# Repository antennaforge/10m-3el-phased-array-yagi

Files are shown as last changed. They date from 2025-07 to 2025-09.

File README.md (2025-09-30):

# 10m-yagi-phased-array

This compact lightweight HF antenna is based on the [3-element yagi design](https://antenna2.github.io/cebik/content/a10/ant53.html) by [LB Cebik, W4RNL (SK)](https://www.qcwa.org/w4rnl-13211-sk.htm) with slight modifications (antenna element materials). Many more of his works can be found [here](https://antenna2.github.io/cebik/content/bookant.html) and [here](https://github.com/antenna2/cebik/tree/main).

## Modifications
1. Use of combination of tent poles and arrow shafts for dipole elements.
2. Use of 3d printed parts
3. Current choke
4. Truss support

## Table of contents
1. Introduction
2. [Bill of materials](Bill-of-materials.md)
3. [Element construction](Elements.md)
4. [Choke](Choke.md)
4. [Phasing harness](Phasing-harness.md)
5. [Truss](Truss.md)
6. [Tuning](Tuning.md)
7. [Testing](Testing.md)
8. [References](References.md)

Have fun learning from building this one.

73 de Herman Tolentino, KQ4ZGQ

## License

- Project design files are released under the [CERN Open Hardware Licence v2 Strongly Reciprocal](LICENSE.md).
- Original LB Cebik reference materials cited above are maintained at [antenna2/cebik](https://github.com/antenna2/cebik) and are shared under the MIT License.

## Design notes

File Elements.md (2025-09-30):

# Element construction - Overview

There are three dipoles (elements):
1. Director Dipole. Based on Cebik medium duty design, this dipole is 191 inches long. A half element is 95.5 inches long. (Prototype half dipole is 95 inches.)
2. Forward-fed Dipole (Driver 2 or D2) 194 inches long, half is 97. (Prototype half dipole is 100.25 inches.)
3. Rear-fed Dipole (Driver 1 or D1) 206 inches long, half is 103. (Prototype half dipole is 108.5 inches.)

For sources of materials for antenna elements, see [Bill of materials](Bill-of-materials.md)

## Connectors
1. Connector 1: Online Metals 1/4 inch OD, 0.035 inch thick aluminum tube cut to 4 inches
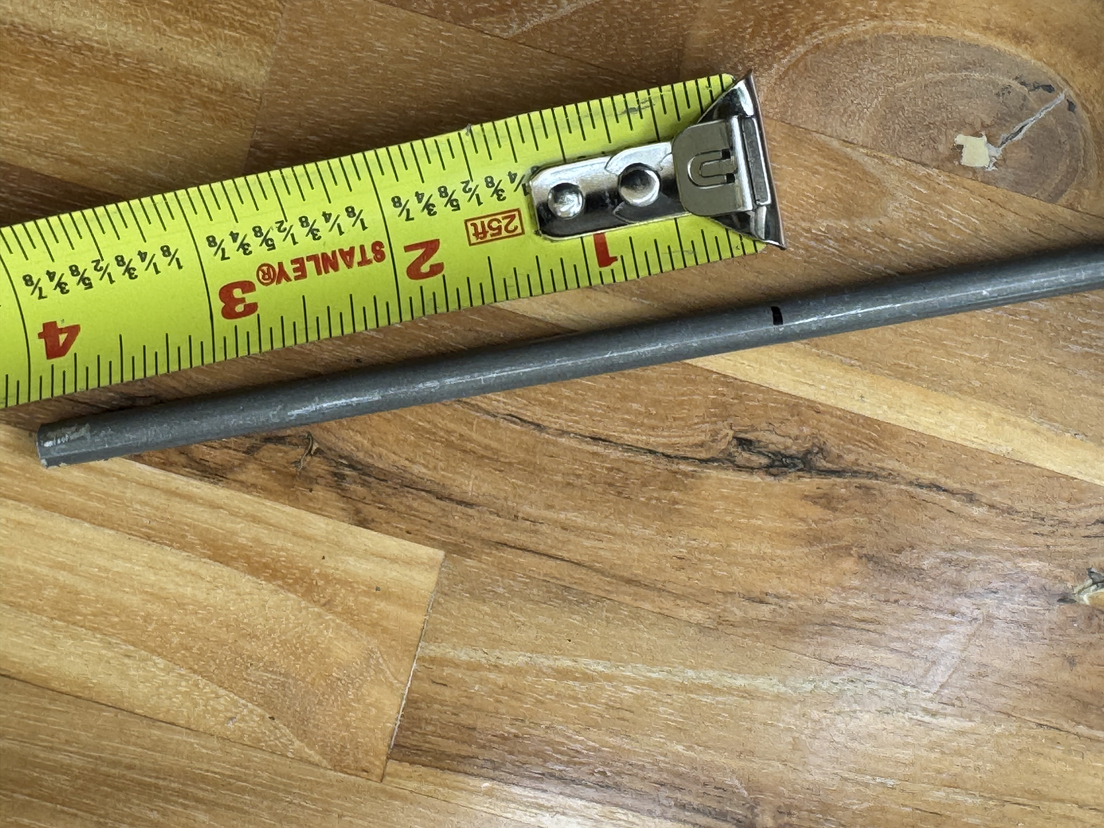
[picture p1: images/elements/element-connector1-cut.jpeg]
 
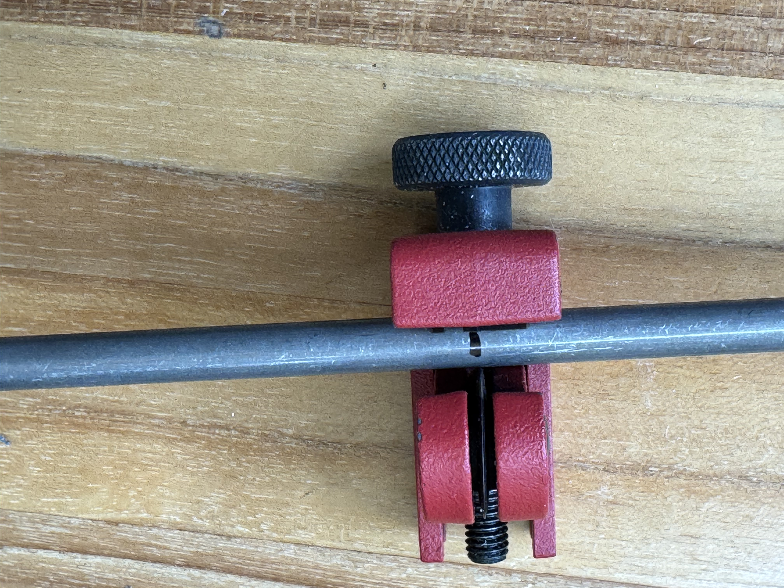
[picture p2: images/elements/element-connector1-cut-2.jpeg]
 

2. Connector 2: Online Metals 1/4 inch OD, 0.035 inch thick aluminum tube cut to 3 inches

## Shims

1. Shim 1: Copper tape shim, cut to 2 inches
2. Shim 2: Copper tape shim, cut to 4 inches (for Connector 1)
3. Shim 3: Copper tape shim, cut to 3 inches (for Connector 2)
4. Shim 4: Copper sheet cut to 1.25 inch by 0.25 inch lengths
 
## Element Segments

Table 1. Element lengths for modified Cebik antenna. All dimensions are in inches. Two inches of the Mid 1 segments overlaps with the root tubes. The tip tubes are used for tuning and can slide into the Mid 3 segments to vary the dipole lengths. 
| Dipole	  | Root	 | Mid 1 | Mid 2 | Mid 3 | Tip |
|---|---|---|---|---|-----|
| Director	  | 13.5	 | 30	 | 30	 | 15	 | 12  |
| Forward-fed |	| 14.5	 | 30	 | 30	 | 16	 | 12  |
| Rear-fed	  | 14.5	 | 30	 | 30	 | 25	 | 12  |

There are 4 segments in each half of the Director dipole. All "Mid" segments are arrow shafts. The root tube is a tent pole. The tip tube is a smaller diameter aluminum tube that slides inside the last arrow shaft.

1. Root segment (tent pole): Cut to 13.5 inches
2. Mid 1 segment (arrow shaft): Keep original length at 30 inches. Two inches of the root side is stripped and covered with 4 sheets of Shim 1 and slides into the tent pole.
3. Mid 2 segment (arrow shaft): Keep original length at 30 inches. This connects to Mid 1 using Connector 1 which is covered with Shim 2. Connector 1 has a 2 inch overlap on each side.   
4. Mid 3 segment (arrow shaft): Cut to 15 inches. This connects to Mid 2 using Connector 2. Connector 2 is covered with 1 and 1/3 sheets of Shim 3 before sliding Mid 3 and Mid 2 over it. Connector 2 has 1.5 inch overlap on each side. 
5. Tip segment (6 mm K&S aluminum tube): Cut to 12 inches. This slides into Mid 3 using Shim 1. This will be the tuning tube, all others are fixed. See Cebik antenna element lengths table below.

## Forward-fed Dipole

There are 4 segments in each half of the Forward-fed dipole. All "Mid" segments are arrow shafts. The root tube is a tent pole. The tip tube is an aluminum tube that slides inside the last arrow shaft.

1. Root segment (tent pole): Cut to 14.5 inches
2. Mid 1 segment (arrow shaft): Keep original length at 30 inches. Two inches of the root side is stripped and covered with 4 sheets of Shim 1 and slides into the tent pole.
3. Mid 2 segment (arrow shaft): Keep original length at 30 inches. This connects to Mid 1 using Connector 1 which is covered with Shim 2. Connector 1 has a 2 inch overlap on each side.   
4. Mid 3 segment (arrow shaft): Cut to 15.5 inches. This connects to Mid 2 using Connector 2. Connector 2 is covered with 1 and 1/3 sheets of Shim 3 before sliding Mid 3 and Mid 2 over it. Connector 2 has 1.5 inch overlap on each side. 
5. Tip segment (6 mm K&S aluminum tube): Cut to 12 inches. This slides into Mid 3 using Shim 1. This will be the tuning tube, all others are fixed. See Cebik antenna element lengths table below.

## Rear-fed Dipole

There are 5 segments in each half of the Rear-fed dipole. All "Mid" segments are arrow shafts. The root tube is a tent pole. The tip tube is an aluminum tube that slides inside the last arrow shaft.

1. Root segment (tent pole): Cut to 14.5 inches
2. Mid 1 segment (arrow shaft): Keep original length at 30 inches. Two inches of the root side is stripped and covered with 4 sheets of Shim 1 and slides into the tent pole.
3. Mid 2 segment (arrow shaft): Keep original length at 30 inches. This connects to Mid 1 using Connector 1 which is covered with Shim 2. Connector 1 has a 2 inch overlap on each side.   
4. Mid 3 segment (arrow shaft): Cut to 18.5 inches. This connects to Mid 2 using Connector 2. Connector 2 is covered with 1 and 1/3 sheets of Shim 3 before sliding Mid 3 and Mid 2 over it. Connector 2 has 1.5 inch overlap on each side. 
5. Tip segment (6 mm K&S aluminum tube): Cut to 12 inches. This slides into Mid 3 using Shim 1. This will be the tuning tube, all others are fixed. Pull the tip in or out of Mid 3 to adjust half-element length. See Cebik antenna element lengths table in [Tuning](Tuning.md) Table 1.

# Preparing elements and Connectors

## Burring and stripping

1. Burr the insides of both ends of arrow shafts  
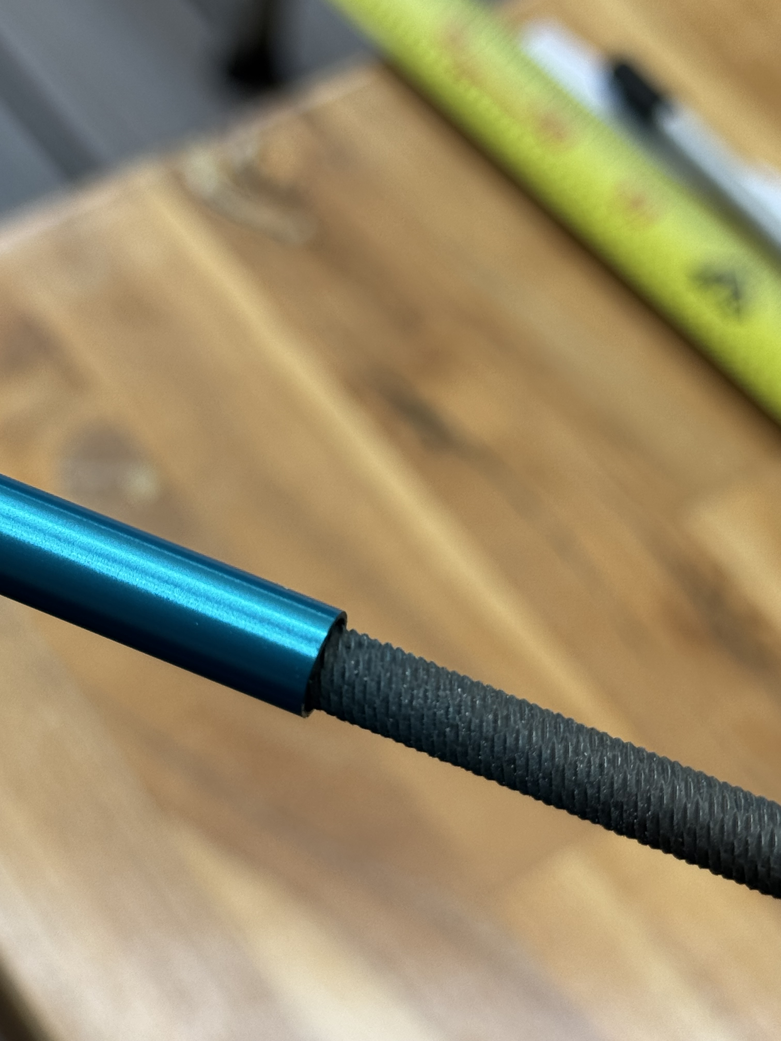
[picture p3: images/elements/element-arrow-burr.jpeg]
 
2. Test that the burring created a conductive path for connectors to work. 
 
3. Do the same for the element side of the root tube, the tent pole. One inch of the boom side of the tent pole is stripped. Test connections as well. 
4. Strip 2 inches from one end of each Mid 1 segment (arrow shaft) to ensure proper fit into the tent pole root segment.

## Stripping

1. Strip 2 inches from the root end of each Mid 1 segment (arrow shaft) to create a snug fit inside the tent pole  
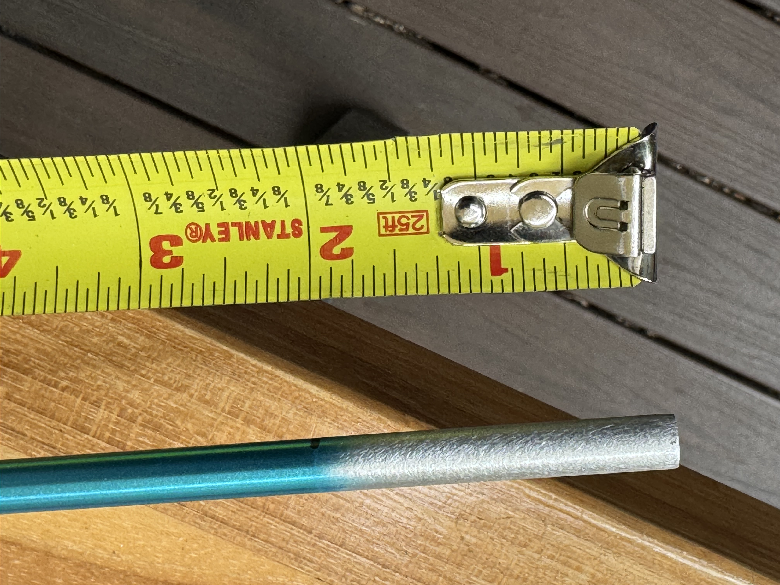
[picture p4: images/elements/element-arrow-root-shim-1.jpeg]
 
2. Apply 4 sheets of Shim 1 (copper tape) around the stripped section before insertion
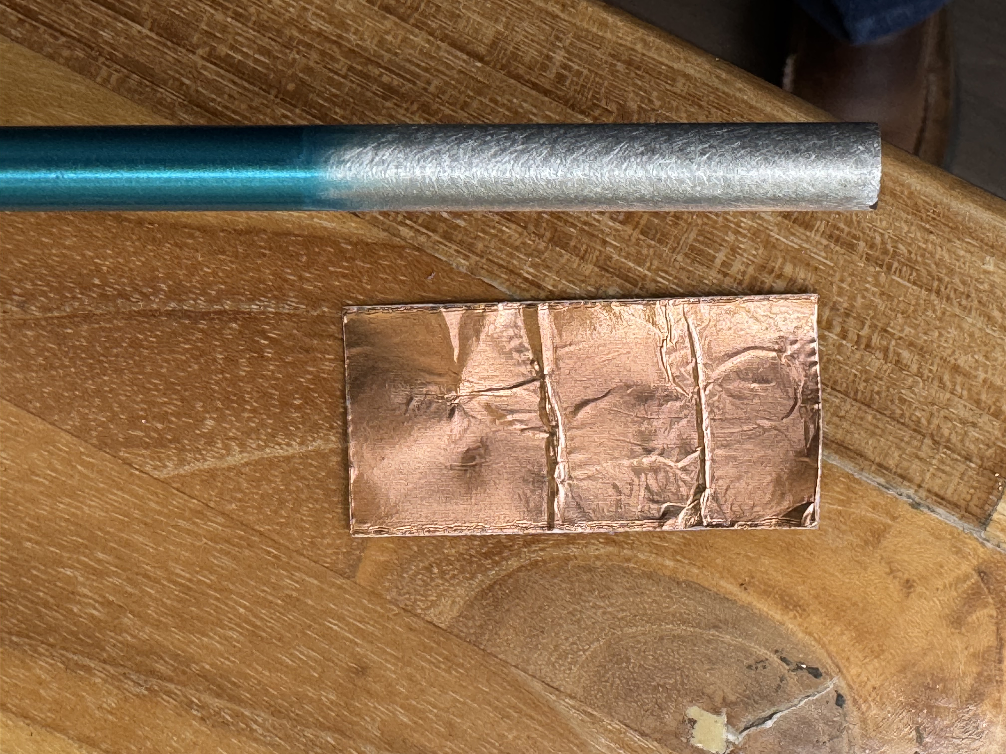
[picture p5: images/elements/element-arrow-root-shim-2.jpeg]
 
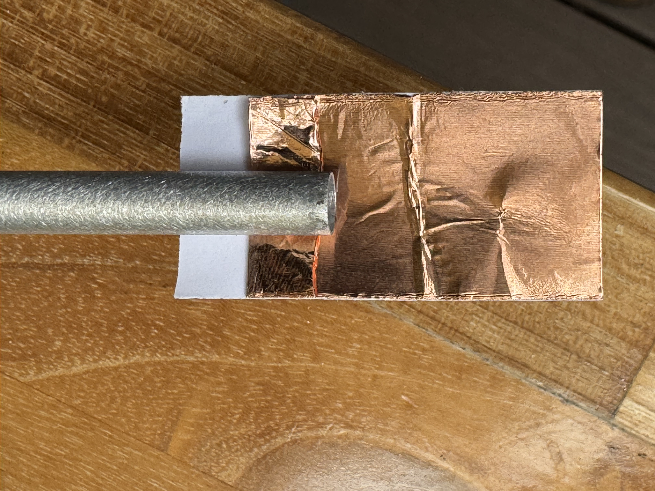
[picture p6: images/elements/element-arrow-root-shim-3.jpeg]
 
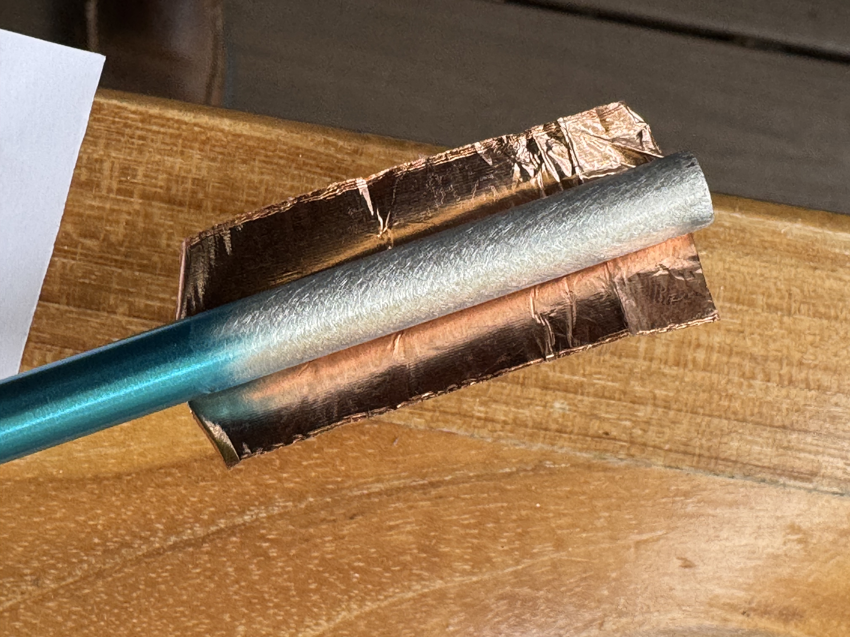
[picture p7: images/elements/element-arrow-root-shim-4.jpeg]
 

3. Ensure snug fit and test all connections to ensure electrical continuity before final assembly.
4. Mark the insertion depth on each segment to ensure consistent lengths assembly and re-assembly.

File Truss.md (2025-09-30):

# Truss

The purpose of the truss system is to prevent excessive sagging of the 3 elements.

## Setting up the truss mast
1. Cut arrow shaft to 15-inch length x 6 (2 per dipole element)
2. Label the pair of masts for each element.

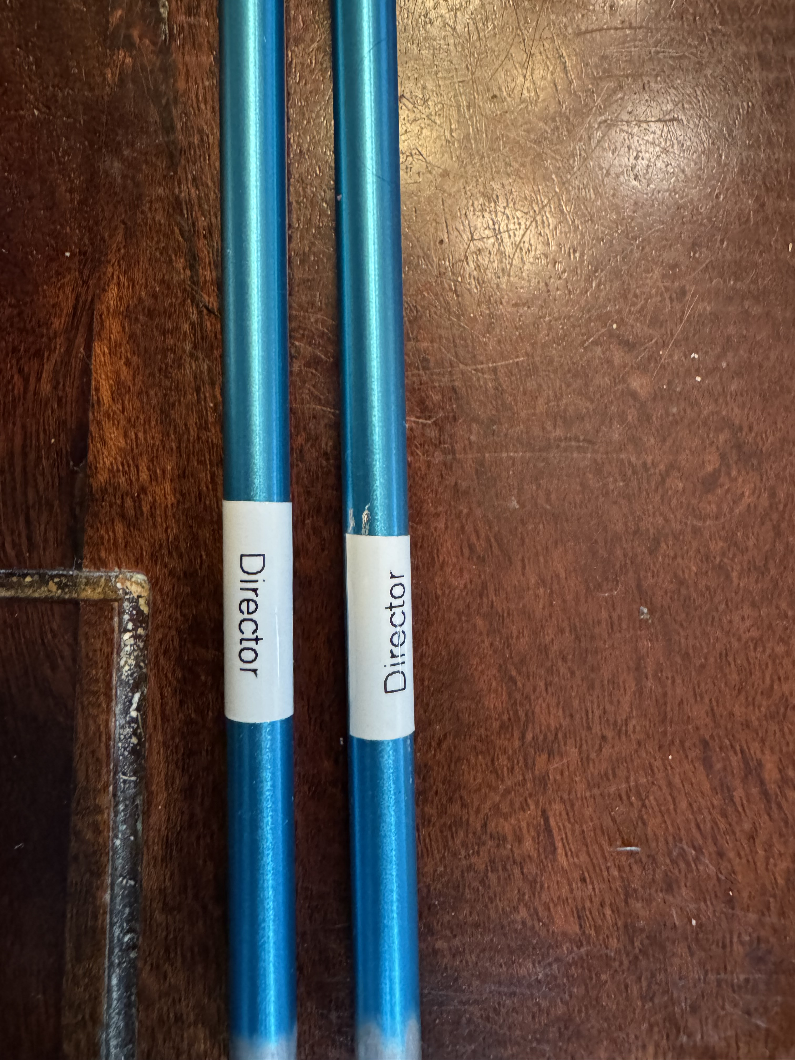
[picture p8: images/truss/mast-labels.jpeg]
 

3. Attach the truss clamp assembly to the mast pair for each element.

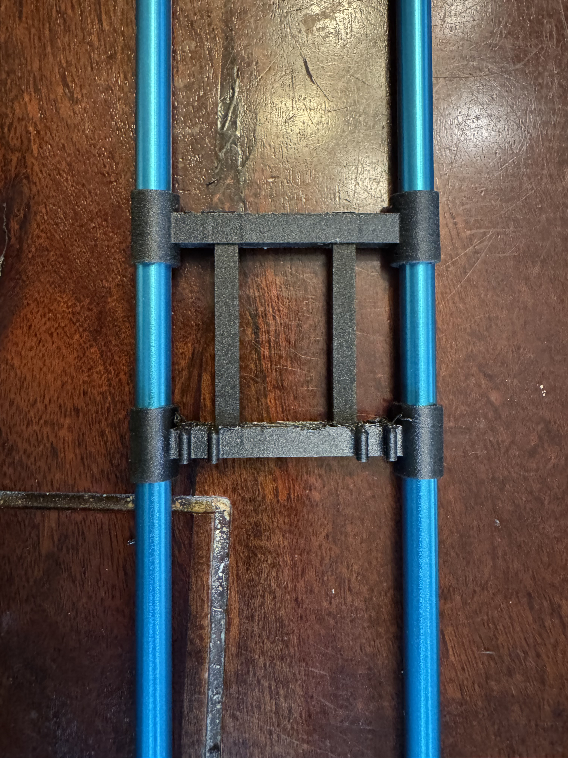
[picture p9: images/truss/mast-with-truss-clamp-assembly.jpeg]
 

## Setting up the paracord

### Paracord and tensioner

1. Cut paracord to lengths corresponding to the elements below:

| Element | Length, inches |
|---|---|
| Rear-fed | 160 |
| Forward-fed | 148 |
| Director | 146 |

2. Attach the tensioner to the ends of each cord using a square knot.

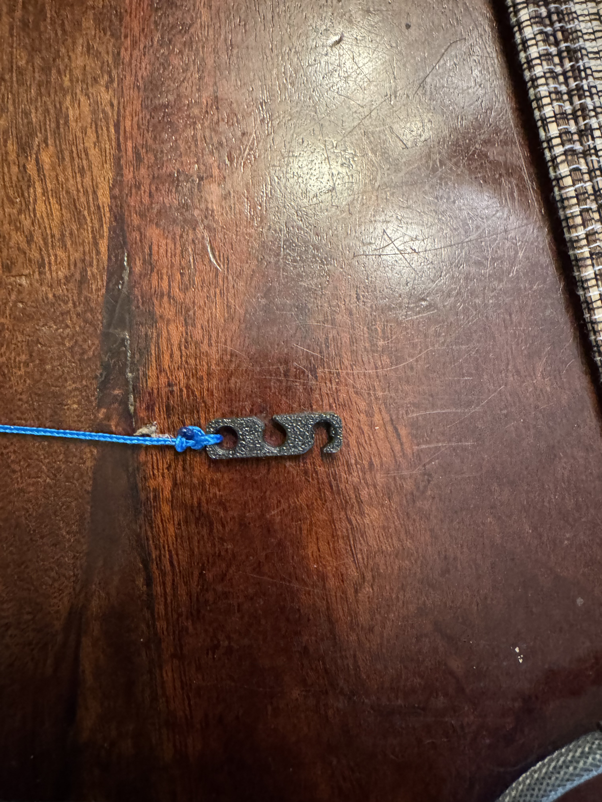
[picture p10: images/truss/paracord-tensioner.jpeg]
 

3. Place the cord clamp on the element half a certain distance from boom according to the table below. Fix the each element cord clamp with a 4-40 machine screw and lock nut - make sure clamps for both element halves are equidistant from the boom.

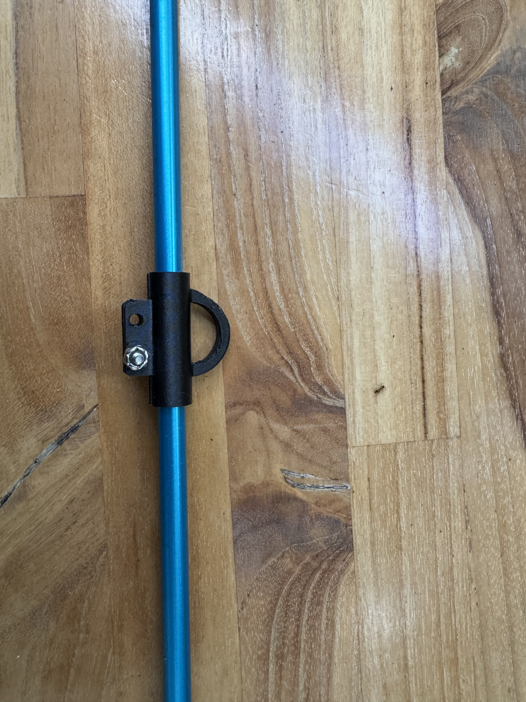
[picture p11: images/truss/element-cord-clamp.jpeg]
 

| Element | Length, inches |
|---|---|
| Rear-fed | 63 |
| Forward-fed | 61 |
| Director | 55 |

4. During assembly insert each mast pair into the corresponding tubes on the truss base.

5. During disassembly, just clip the tensioner on the mast clip to prevent accidental unwinding and messy cord tangles.

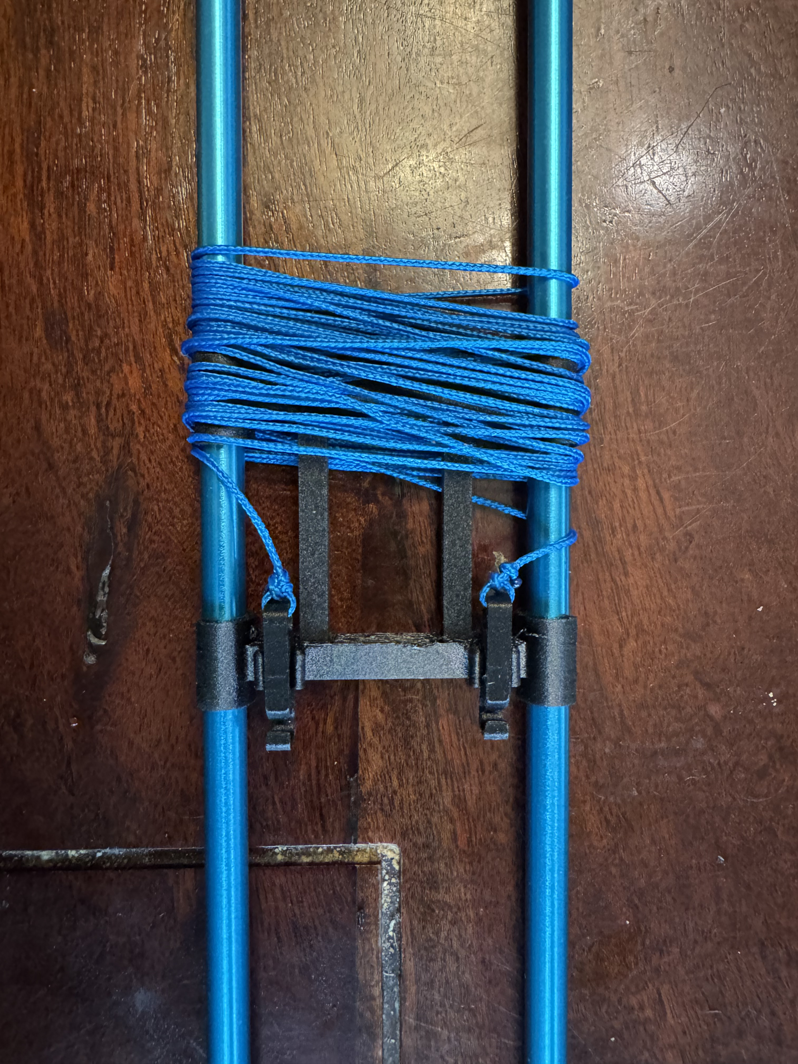
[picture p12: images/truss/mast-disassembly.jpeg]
 

6. Disassembled masts with cord wrapped around each pair. 



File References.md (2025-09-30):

# References

1. [Cebik LB (W4RNL, SK) (2008). A Short Boom, Wideband, *Three Element Yagi for 10 Meters*.](https://www.arrl.org/files/file/Product%20Notes/Antenna_Compendium_Vol_8/Cebik2a.pdf) Last accessed 19 July 2025.
2. Common mode chokes (G3TXQ) - http://www.karinya.net/g3txq/chokes/#measurement. Last accessed 30 Sept 2025.

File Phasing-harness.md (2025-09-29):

# Phased array configuration

The phased array is based on the Cebik antenna described in the [References](References.md) section. Follow wire specs, spaving and building instructions closely.

**Figure 1.** Phasing harness on the antenna boom. Note the half-twist somewhere in the middle.  
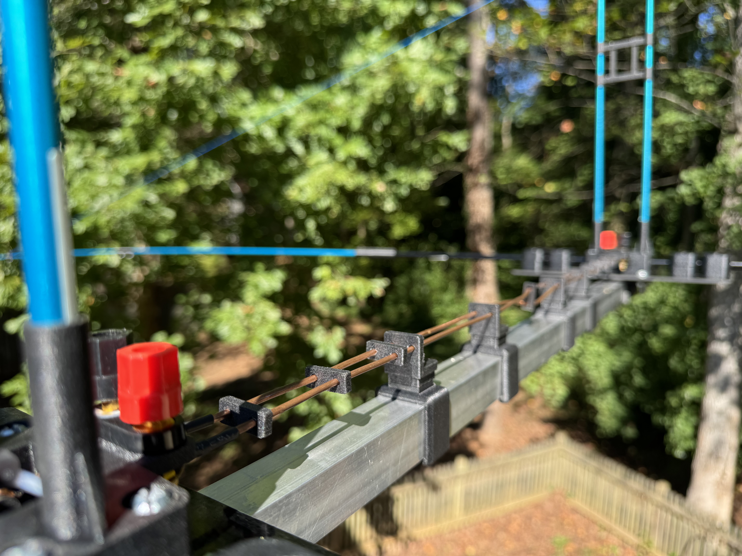
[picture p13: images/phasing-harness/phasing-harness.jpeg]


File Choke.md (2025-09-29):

# Building the current choke

1. See [Bill of Materials](Bill-of-materials.md) for Choke
2. Wind 7-8 turns of RG400 on an FT240-31 ferrite core. Keep the coax pigtails as short as possible. (See Figure 1 below) 
3. Add ferrite beads on the feedpoint coax. (See Figure 2a and 2b)

**Figure 1.** Ferrite core choke balun on the antenna  


**Figure 2a.** Ferrite beads on the feedpoint coax  


**Figure 2b.** Ferrite beads on the feedpoint coax  


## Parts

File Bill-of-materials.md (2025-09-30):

# Bill of materials

## Antenna Dipole Elements

1. Tent poles (1 pack, good for 2 antennas): https://www.amazon.com/dp/B0D17T46FL?th=1
2. Arrow shafts / truss masts (pack of 12, need 2 sets): https://www.amazon.com/dp/B07L5M5MLR
3. Aluminum tube (tip) and element connectors, 1/4 inch OD, 0.035 inch thick, 3 feet x 5: https://www.mcmaster.com/catalog/131/4227/9056K61. For tuning tips, cut 3 of 3 foot tubes into 2 equal halves. Use the remaining 2 3-foot tubes for arrow shaft connectors.   
4. Antenna boom, aluminum square tube, 1 inch x 1 inch x 6 feet: https://www.mcmaster.com/catalog/131/4228/6546K53. Cut to 5 feet length.

## Truss
1. Paracord (see [Truss.md](Truss.md) for estimating cord lengths) - https://www.amazon.com/dp/B0D1DHBP4F
2. Arrow shafts (see above)

## Copper conductors

1. Copper sheet: https://www.amazon.com/uxcell-Flashing-Electricity-Projects-Multiple/dp/B0C55HNVV6
2. Copper tape: https://www.amazon.com/dp/B097HHJQPS
3. Copper wire 18AWG: https://www.amazon.com/dp/B08QG84CWQ
4. Copper wire 10AWG: https://www.amazon.com/dp/B0CC5742QQ
   
## Screws and Brass Inserts
1. Screws  
   1.1 Element clamps: 10-32, 1.25 inches x 24 - https://www.amazon.com/Stainless-Phillips-Machine-Bolt-Dropper/dp/B07D1L49NR   
   1.2 Truss base: 10-32, 1.5 inches x 12 - https://www.amazon.com/Glvaner-Thread-Phillips-Machine-Stainless/dp/B09B75WRXX  
   1.3 Truss base, terminal: 10-32, 3/4 inch x 6 - https://www.amazon.com/Phillips-Machine-Stainless-Thread-RoyceMart/dp/B08GH98YPS/    
   1.4 Element plate to boom clamp: 10-32, 3/4 inch x 12 (same as above)  
   1.5 Boom clamp brass inserts: 8-32, 1/2 inch x 10 - https://www.amazon.com/Phillips-Machine-Screws-Stainless-Quantity/dp/B0894BY3SF/  
   1.6 Boom to mast clamp: 10-32, 1.5 inches x 4 (same as 1.2)  
   1.7 Element clamps: 4-40, 1/2 inch x 54 - https://www.amazon.com/dp/B09B74Y13V?   
   1.8 Lock nuts, 10-32 -  https://www.amazon.com/Vifmy-Insert-Locknuts-Stainless-Standard/dp/B0CPHW89YP/  
   1.9 Lock nuts, 4-40 - https://www.amazon.com/dp/B085N483D1  

2. Brass inserts: 8-32, 1/4 inch x 8 - https://www.amazon.com/ruthex-8-32-Threaded-Inserts-RX-8-32x8-1/dp/B0CG4K9FM5/

## Choke
1. Ferrite toroid 240-31 - https://www.amazon.com/dp/B0F6DG2H5S  
2. RG400 coax - https://www.amazon.com/dp/B08N17KGK1  
3. SO239 connector - https://www.amazon.com/dp/B08F772R48  
5. Terminal lug, M5 - https://www.amazon.com/dp/B0DC6JP5BW  
6. Ferrite beads on coax - https://www.amazon.com/dp/B0C9QXBS3J
   
## 3D Filaments
1. PETG-CF -

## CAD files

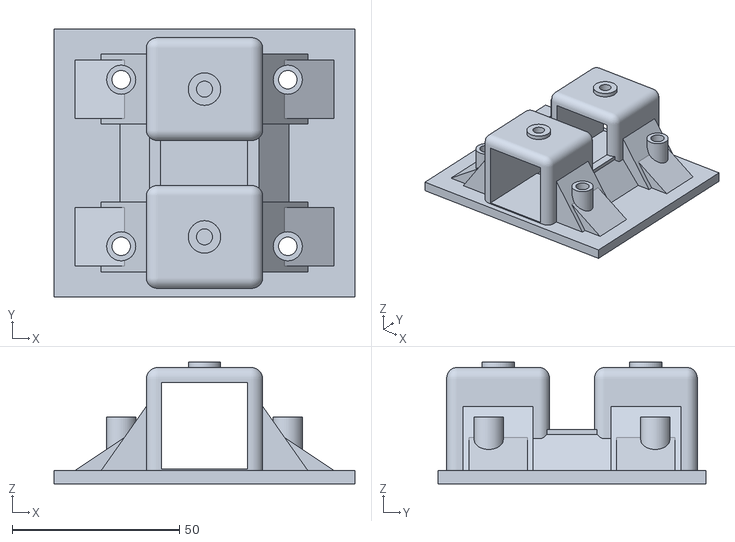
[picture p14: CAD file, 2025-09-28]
stl/10m-yagi-boom-mast-clamp.stl
90.0 x 80.0 x 36.4

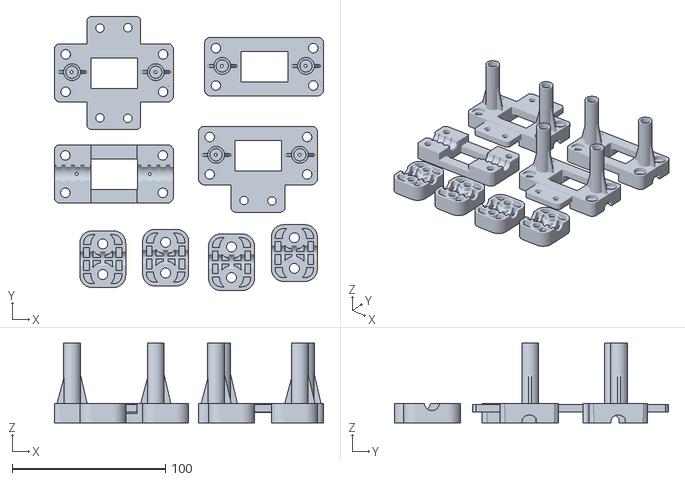
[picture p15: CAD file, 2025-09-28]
stl/10m-yagi-truss-base-V2.stl
175.5 x 178.9 x 52.0

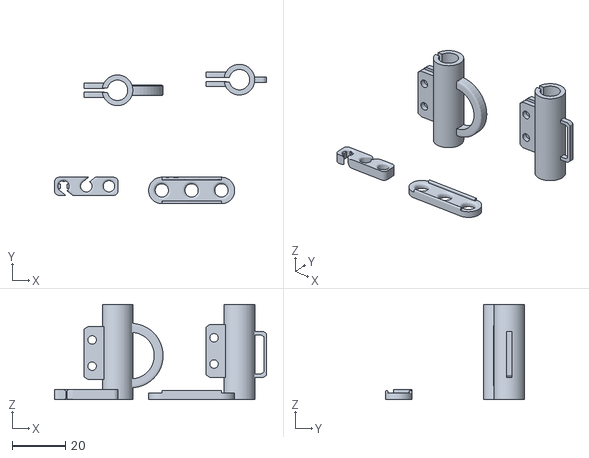
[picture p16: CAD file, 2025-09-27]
stl/10m-yagi-rope-tensioner.stl
80.0 x 52.6 x 36.0

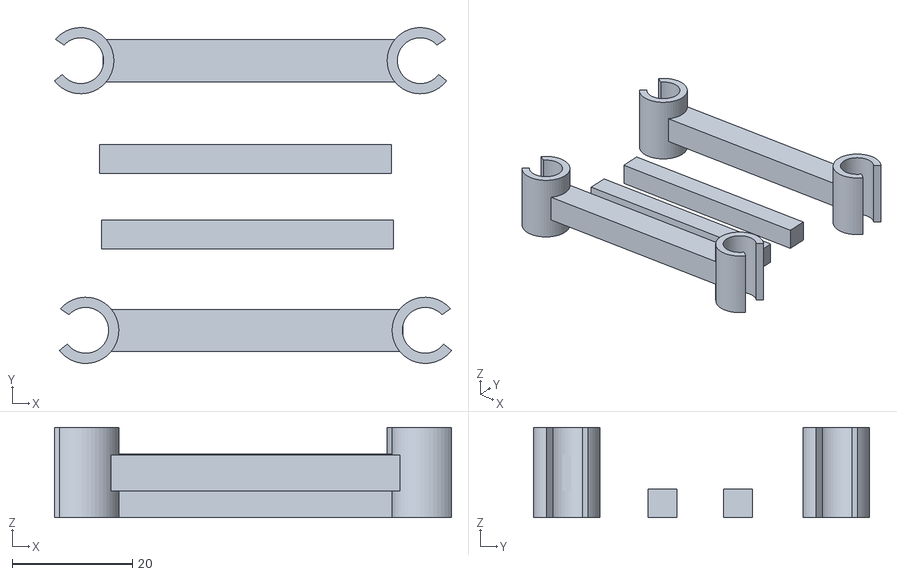
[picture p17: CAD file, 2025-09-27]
stl/10m-yagi-truss-accessories.stl
65.9 x 55.8 x 15.0

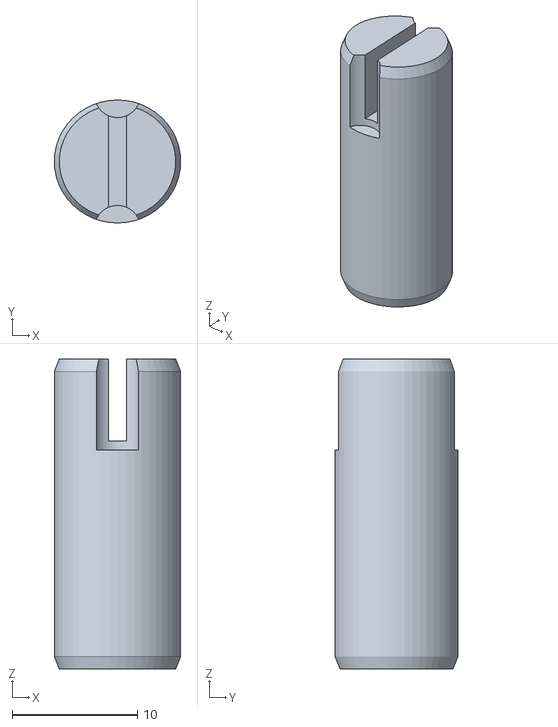
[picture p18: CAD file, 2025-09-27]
stl/10m-yagi-petg-element-cap.stl
10.1 x 9.82 x 24.8

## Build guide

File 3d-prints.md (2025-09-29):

# 3D-Printed Parts

## Truss parts
1. Truss cap  
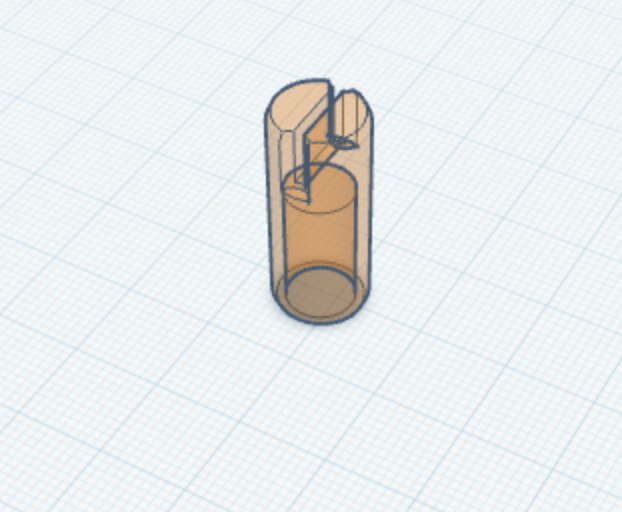
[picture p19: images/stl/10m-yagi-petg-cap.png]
[](stl/10m-yagi-petg-element-cap.stl)
2. Truss accessories  
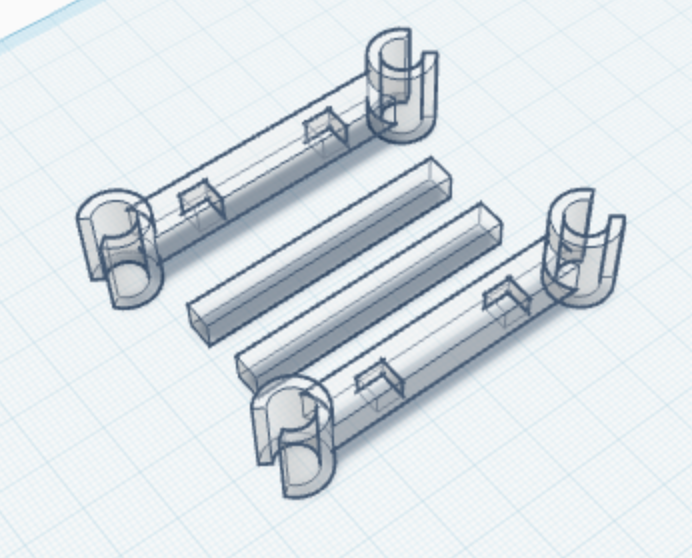
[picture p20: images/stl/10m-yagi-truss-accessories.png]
[](stl/10m-yagi-truss-accessories.stl)
3. Rope tensioner  
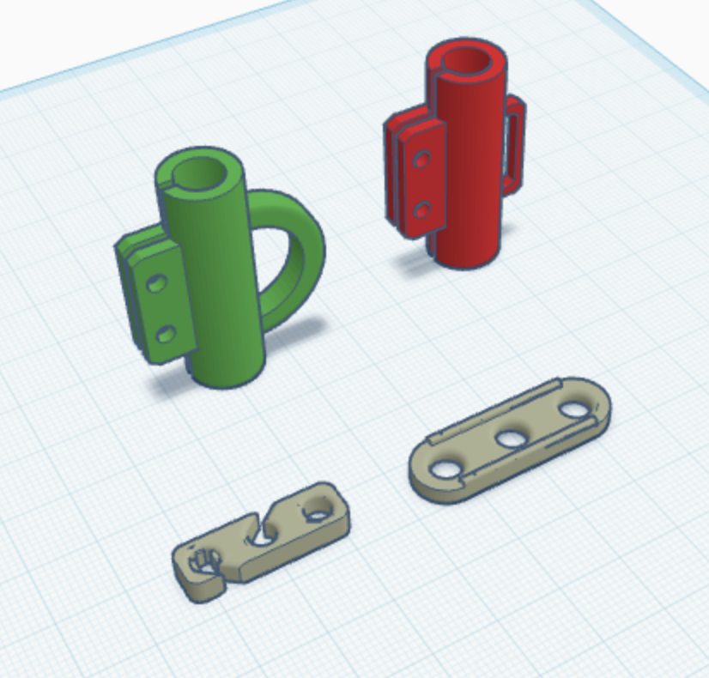
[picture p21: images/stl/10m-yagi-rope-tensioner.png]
[](stl/10m-yagi-rope-tensioner.stl)  

4. Truss base  
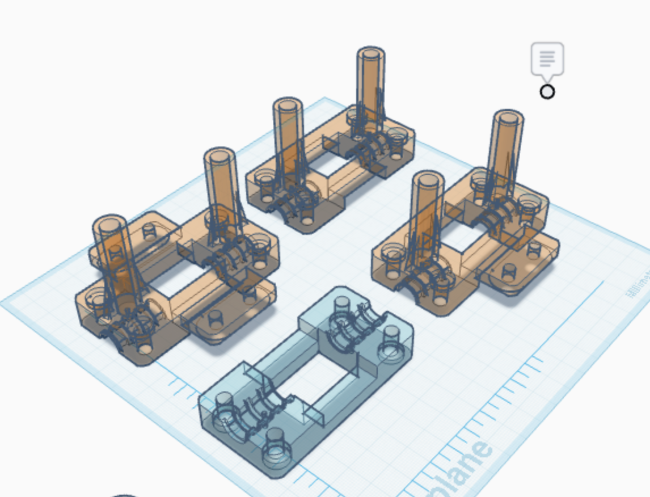
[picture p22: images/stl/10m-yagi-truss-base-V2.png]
[](stl/10m-yagi-truss-base-V2.stl)  

## Element parts

## Phasing harness parts

## Boom parts

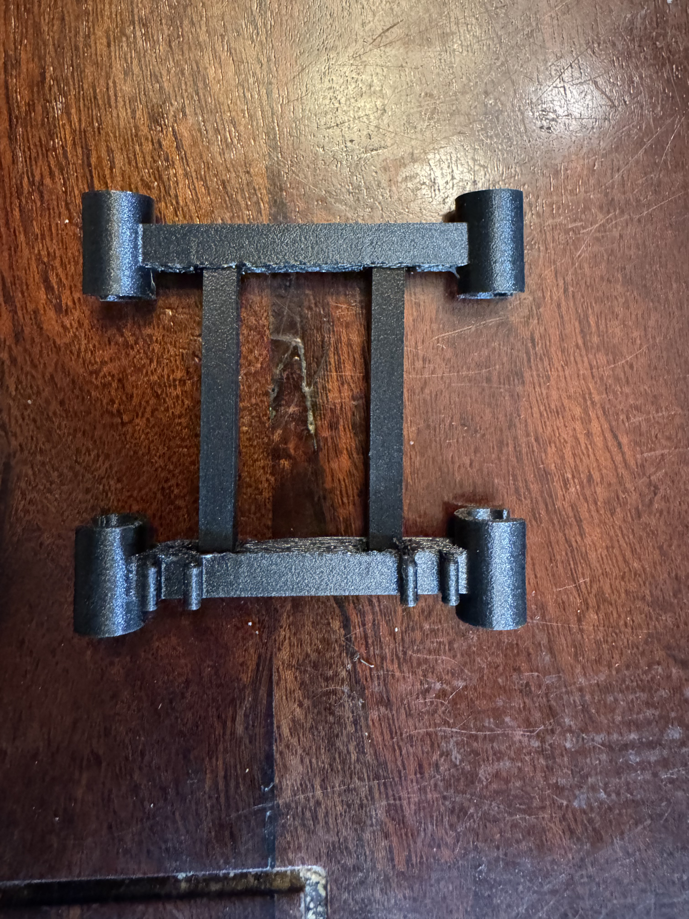
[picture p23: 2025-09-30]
images/truss/truss-clamp-assembly.jpeg

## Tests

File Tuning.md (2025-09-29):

# Tuning the antenna

## Preparation
1. Have a Google spreadsheet or pen and paper ready. 
2. Assembled yagi antenna on a mast or low height tripod (as far away from ground but low enough to make length adjustments). 
3. Equipment below

## Procedure

### Equipment
1. RigExpert or NanoVNA
2. Multimeter
3. Tape measure
4. Spreadsheet or pen and paper (notepad)
5. Sharpie pen
   
### Measurements 

Adjusted tuning sequence (with length asymmetry in mind)
1.	Check mechanical assembly  
    1.1 Confirm rear-fed element is installed as indeed the longer one. (I label them with Brother P-Touch label printer. You can label them with Sharpie pen also.)  
	1.2 Confirm forward-fed element is the shorter one.  
2.	Resonance check individually  
    2.1 Start from Prototype element length measurements (See Table 1). The Prototype yagi has the similar materials used for elements and phasing harness and optimal performance measurements.  
	2.2 Rear-fed element (also acts as reflector) → should resonate slightly below the design frequency (~28.2 MHz if targeting 28.4).  
    2.3 For attaching the RigExpert to the feedpoint, use the shortest coax stub possible. Connect the RigExpert to the antenna feedpoint. Record the SWR measurements from RigExpert. Go back to 2 until lowest SWR obtained for desired frequency.  
	2.4 Forward-fed element → should resonate slightly above design frequency (~28.6 MHz if targeting 28.4).  
	2.5 Don’t force elements to be equal — the offsets are intentional in yagi antennas. (See Table 1 below)  
3.  Ensure electrical continuity in all elements, phasing harness (multimeter ohm meter). 
4.	Phasing harness connection  
	4.1 Verify coax lengths/phasing line are correct.  
	4.2 Choke at forward feedpoint, equal lead lengths.
5.	Antenna array measurement  
	5.1 Combined SWR dip should land close to design center (~28.4).  
	5.2 If dip is too low in frequency → trim the forward-fed element slightly.  
	5.2 If dip is too high → lengthen the rear-fed element slightly.  
6.	Pattern verification  
    6.1 Test the antenna with your radio. (Antenna is tuned for FT8 communications so fire up WSJT-X.) See also [Testing.md](Testing.md)  
	6.2 Rotate between forward azimuth and 180° opposite.  
	6.3 Front/Back >15 dB confirms the length asymmetry is correct.  
7. Mark point where the tip inserts into the next element to record last known placement with good SWR.

#### Practical tip

When trimming, always do it in small increments (0.25 inch at a time). Since only the tip sections are adjustable, you can sneak up on the proper offset. Notice that only the director length had to be increased, the other two elements were reduced in length. 

**Table 1.** Element lengths from Cebik and Prototype antennas. AF-C3-V1 (Bennett) is this modified Cebik antenna. All dimensions are in inches. The final dimensions for Yagi AF-C3-V1 are derived from incremental tuning in Table 2 below.

| Source	| Element	  | Dipole	| Half-dipole	| Proportions (* rear-fed reference) |
|---|---|---|---|---|
| Cebik	 | Rear-fed	  | 206	 | 103	 | 1.00 * |
| Cebik	 | Forward-fed | 194	 | 97	 | 0.94 |
| Cebik	 | Director	  | 191	 | 95.5	 | 0.93 |
| Prototype	| Rear-fed	  | 217	 | 108.5	 | 1.00 * |
| Prototype	| Forward-fed |	200.5	| 100.25	 | 0.92 |
| Prototype	| Director	  | 190	 | 95	 | 0.88 |
| AF-C3-V1	| Rear-fed	  | 214.5	| 107.25	 | 1.00 * |
| AF-C3-V1	| Forward-fed | 197.74	| 99.22	 | 0.92 |
| AF-C3-V1	| Director	  | 191.07	| 95.54	 | 0.89 | 

**Table 2.** Incremental tuning data for AF-C3-V1 - observing SWR with incremental changes in element lengths. All units are in inches, except for proportions and SWR. Legend: L = left, R = right, T = total, FF = forward-fed, RF = rear-fed, D = director, SWR = Standing Wave Ratio. Bracketed figures are the right element lengths.

| Rear-fed-T | Cebik RF delta | Forward-fed-T | Cebik FF delta | Director-T | Cebik D delta | SWR-28097@2500 |
|---|---|---|---|---|---|---|
| 214.88 | 8.88 | 198.24 | 4.24 | 191.07 | 0.07 | 1.47 |
| 213.06 | 7.06 | 198.24 | 4.24 | 191.07 | 0.07 | 1.42 |
| 214.5 | 8.5 | 198.24 | 4.24 | 191.07 | 0.07 | 1.43 |
| [214.5] | 8.5 | [197.74] | 3.74 | [191.07] | 0.07 | [1.17] |
| 214.5 | 8.5 | 198.43 | 4.43 | 191.07 | 0.07 | 1.43 |

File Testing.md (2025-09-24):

# Testing

## Test details

1. Antenna: 10m 3-element phased array Yagi (Cebik compact design)
2. Antenna height: On mast 162+150 inches AGL
3. Radio: Yaesu FT991A

## GridTracker2 FT8 Screenshots

### Australia

Figure 1. 250 degrees azimuth, 35w

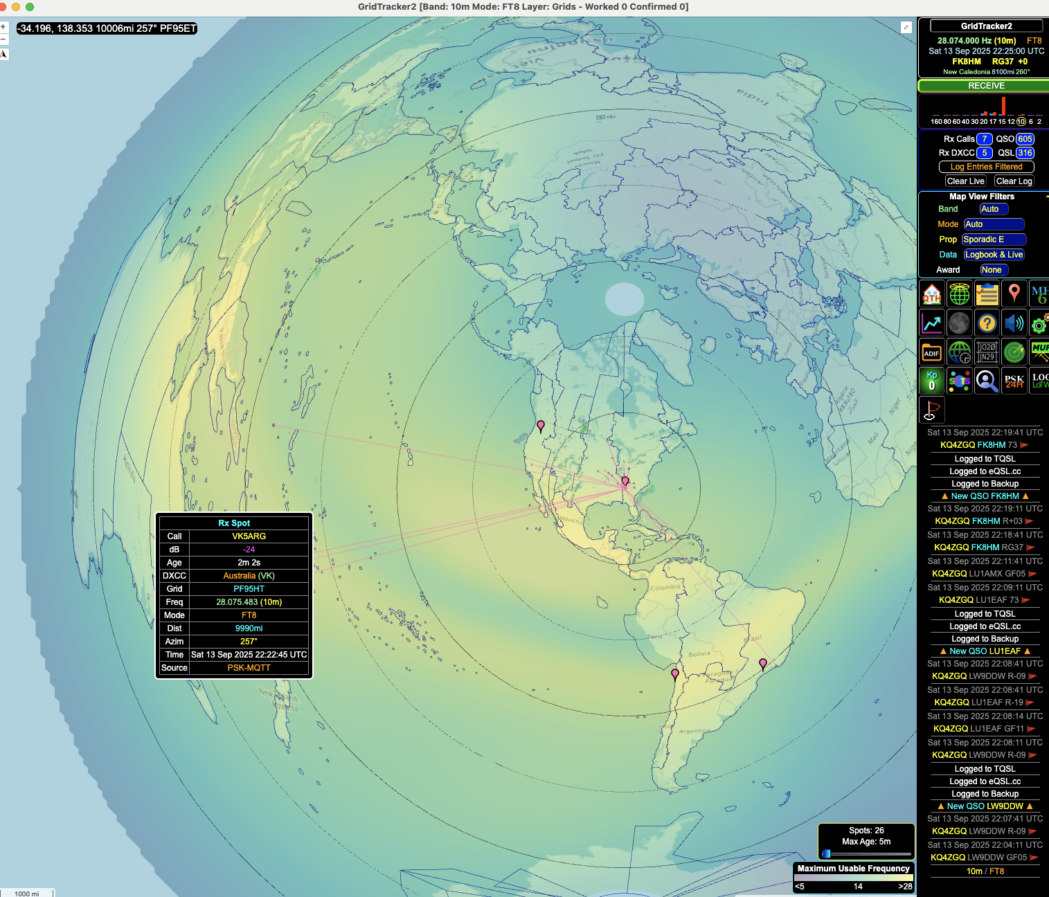
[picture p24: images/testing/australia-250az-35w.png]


Figure 2. 250 degrees azimuth, 60w

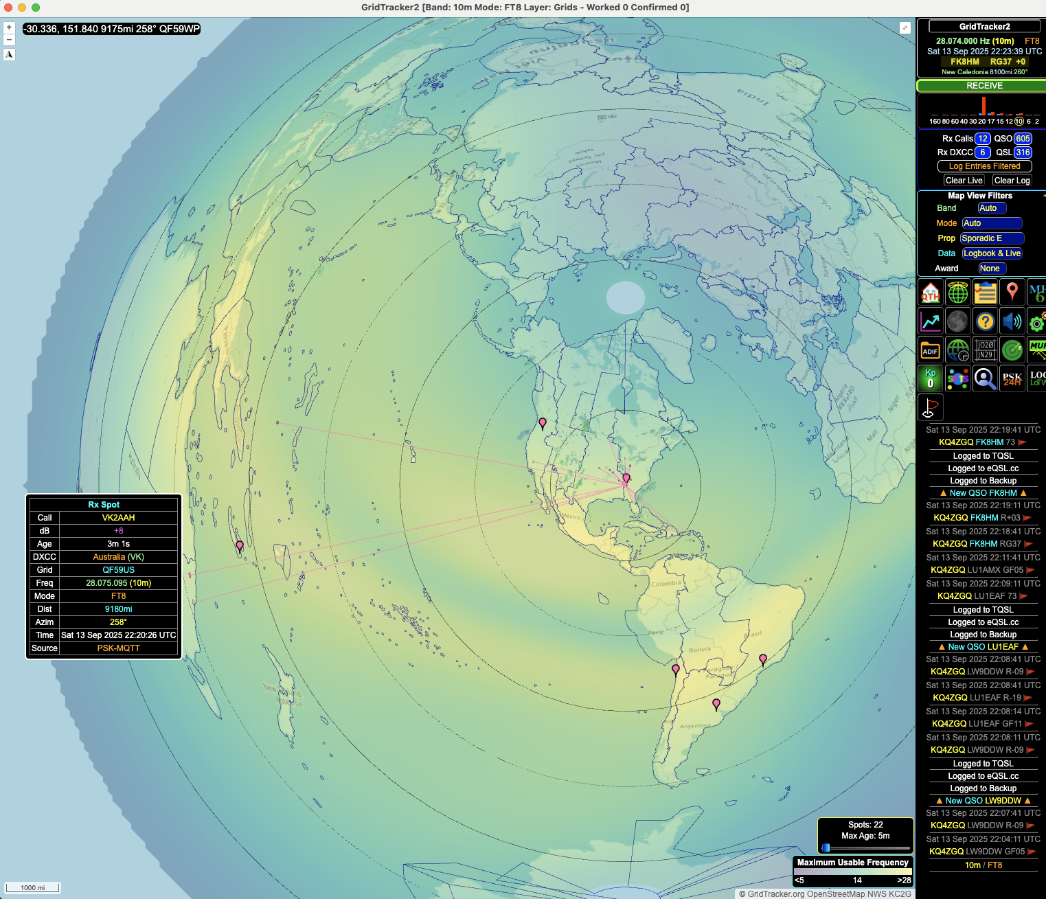
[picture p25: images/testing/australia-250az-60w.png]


### Brazil

Figure 3. 150 degrees azimuth, 50w

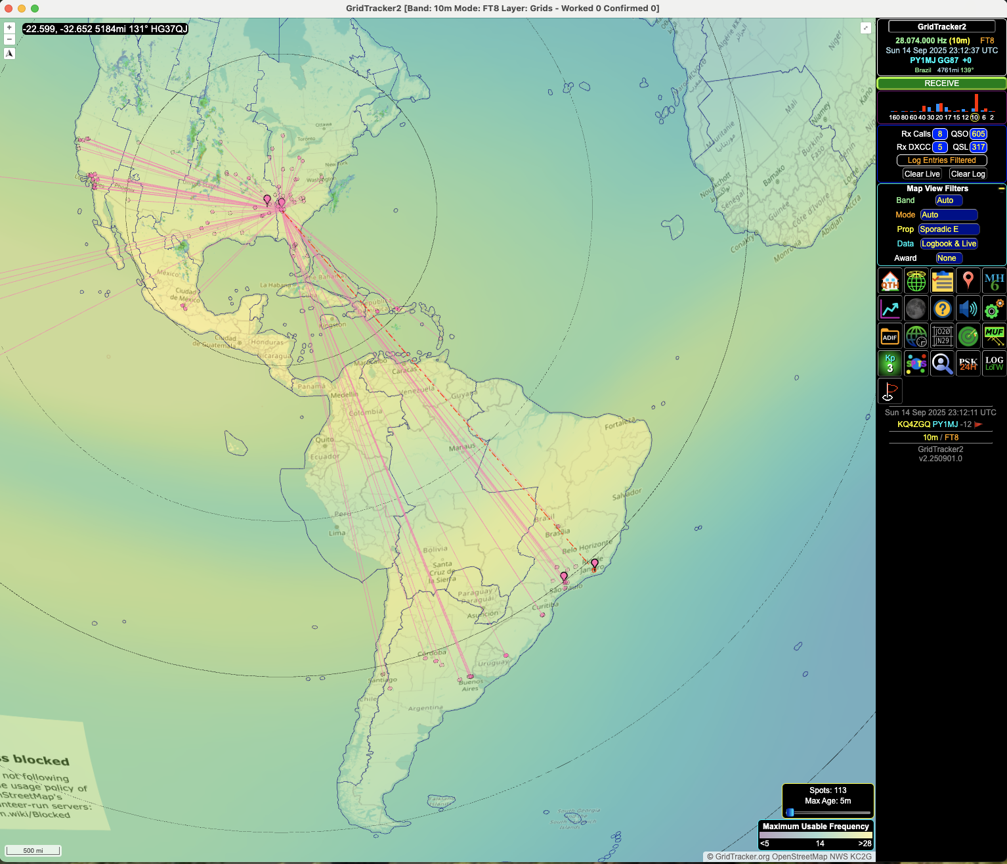
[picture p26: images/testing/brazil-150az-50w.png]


### Indonesia, Japan, Chile

Figure 4. Multiple QSOs at 330 degrees azimuth, 100w

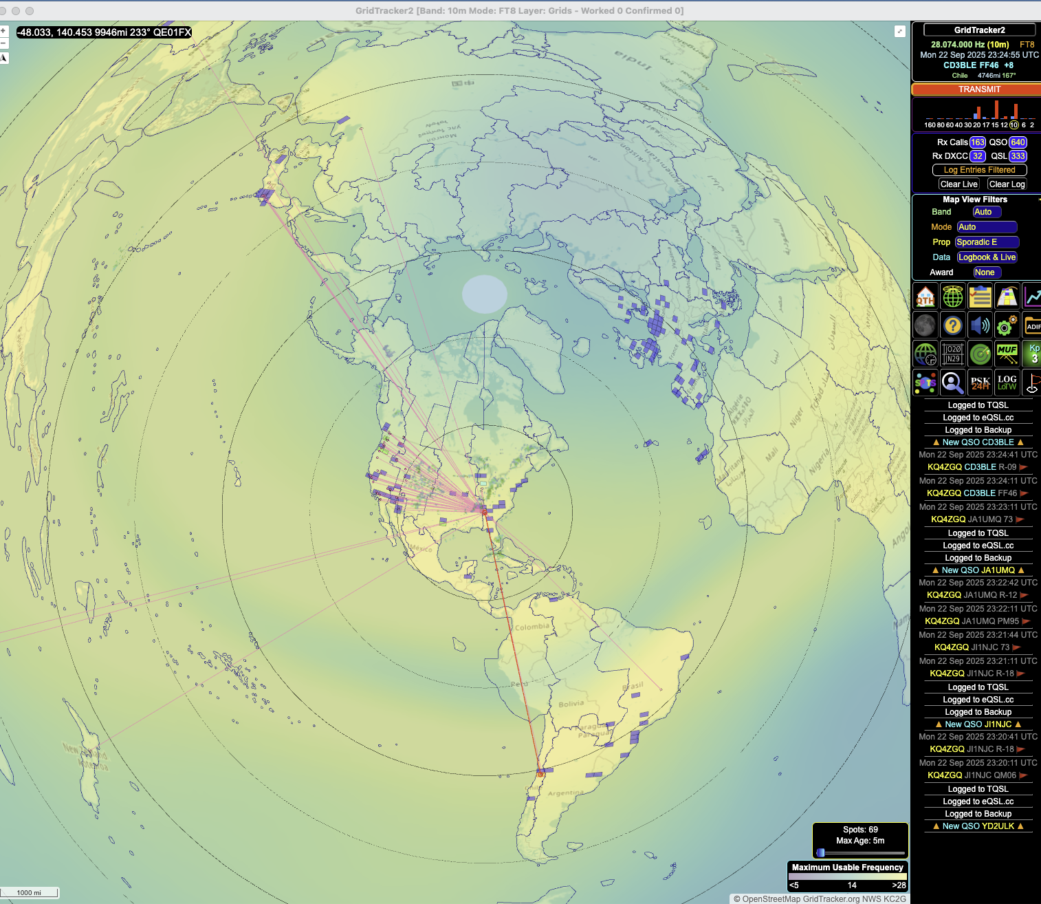
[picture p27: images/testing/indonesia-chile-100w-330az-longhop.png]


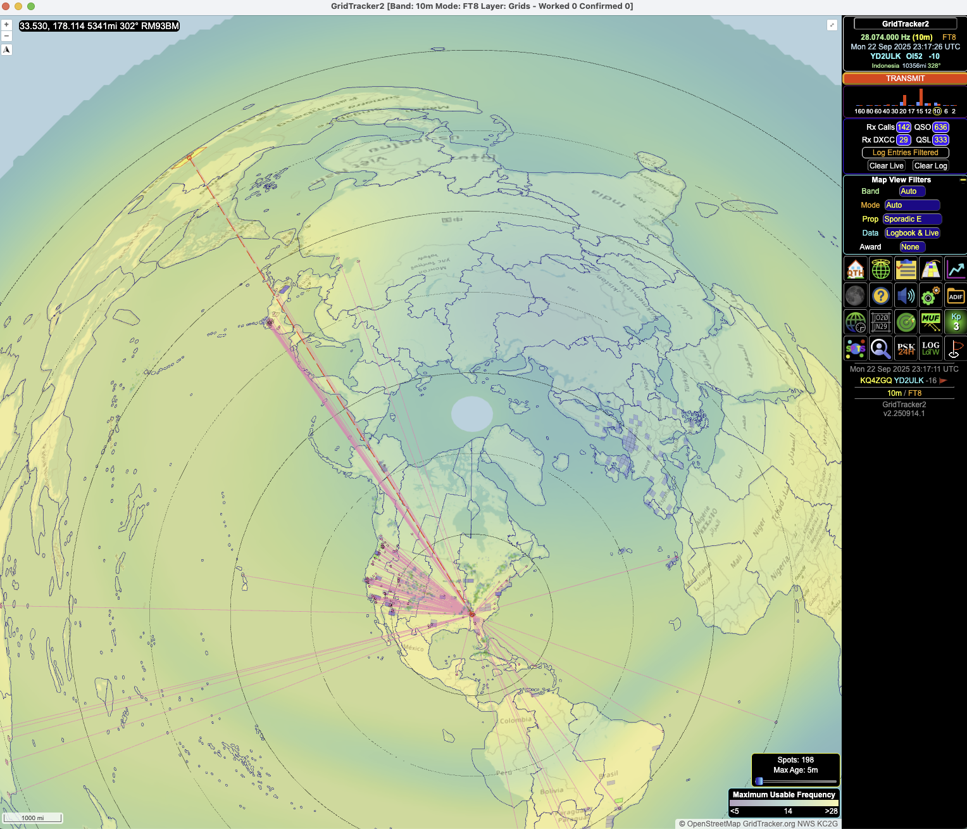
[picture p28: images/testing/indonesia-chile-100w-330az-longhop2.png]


### Greece

Figure 5. 40 degrees azimuth, 100w

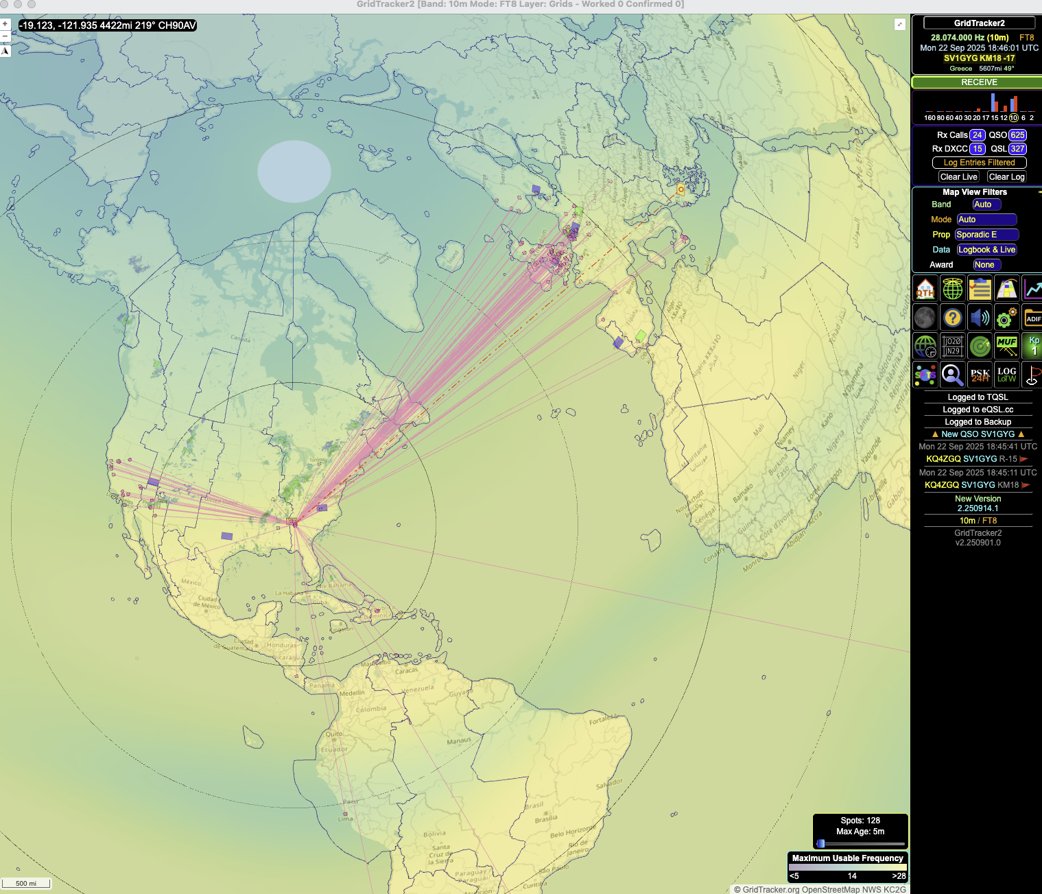
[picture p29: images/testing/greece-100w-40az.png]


### New Zealand

Figure  6. 240az at 100w

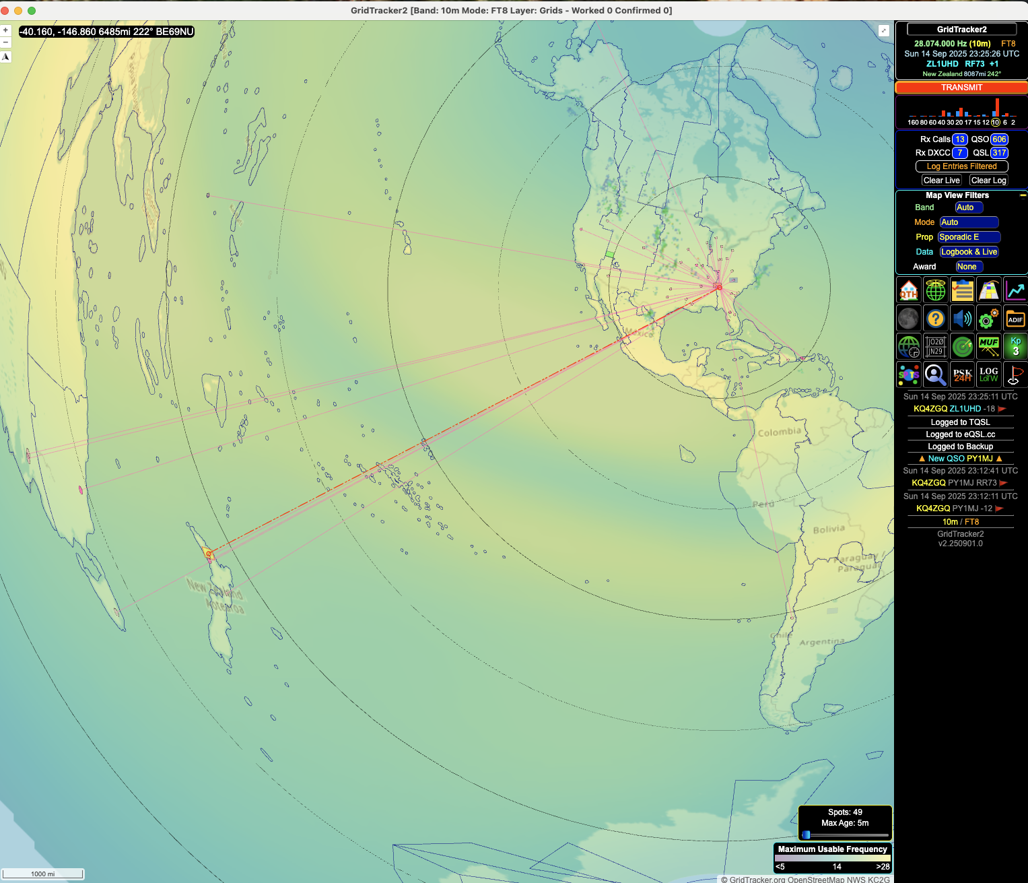
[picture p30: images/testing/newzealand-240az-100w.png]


## WSJT-X QSOs

Figure 6. WSJT-X QSOs

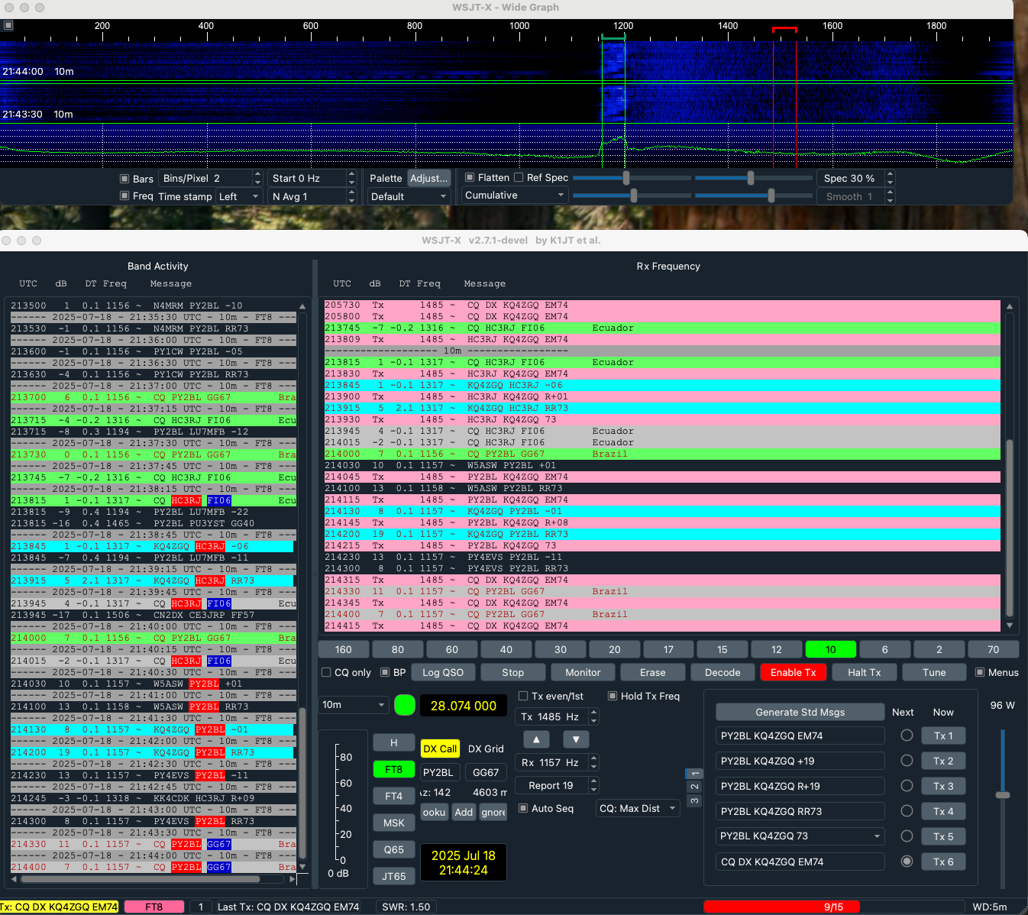
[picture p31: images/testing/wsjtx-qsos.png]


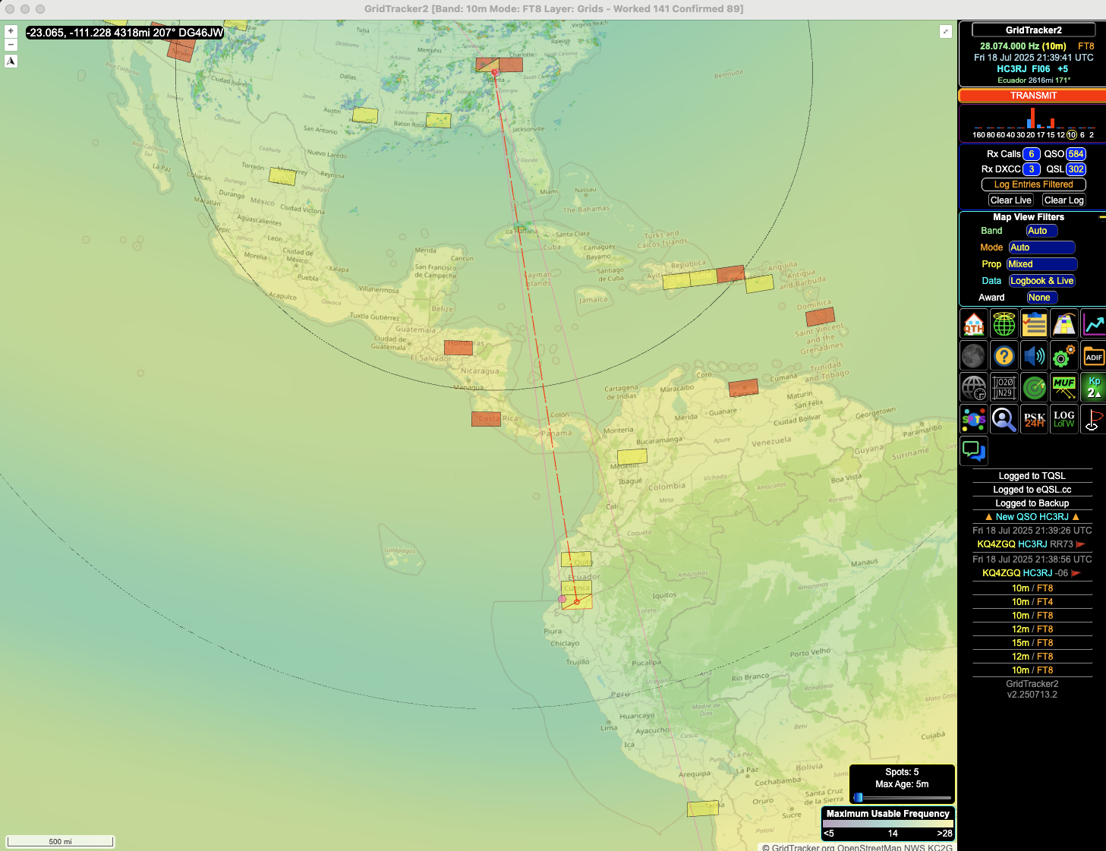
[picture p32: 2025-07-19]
images/testing/ecuador.png

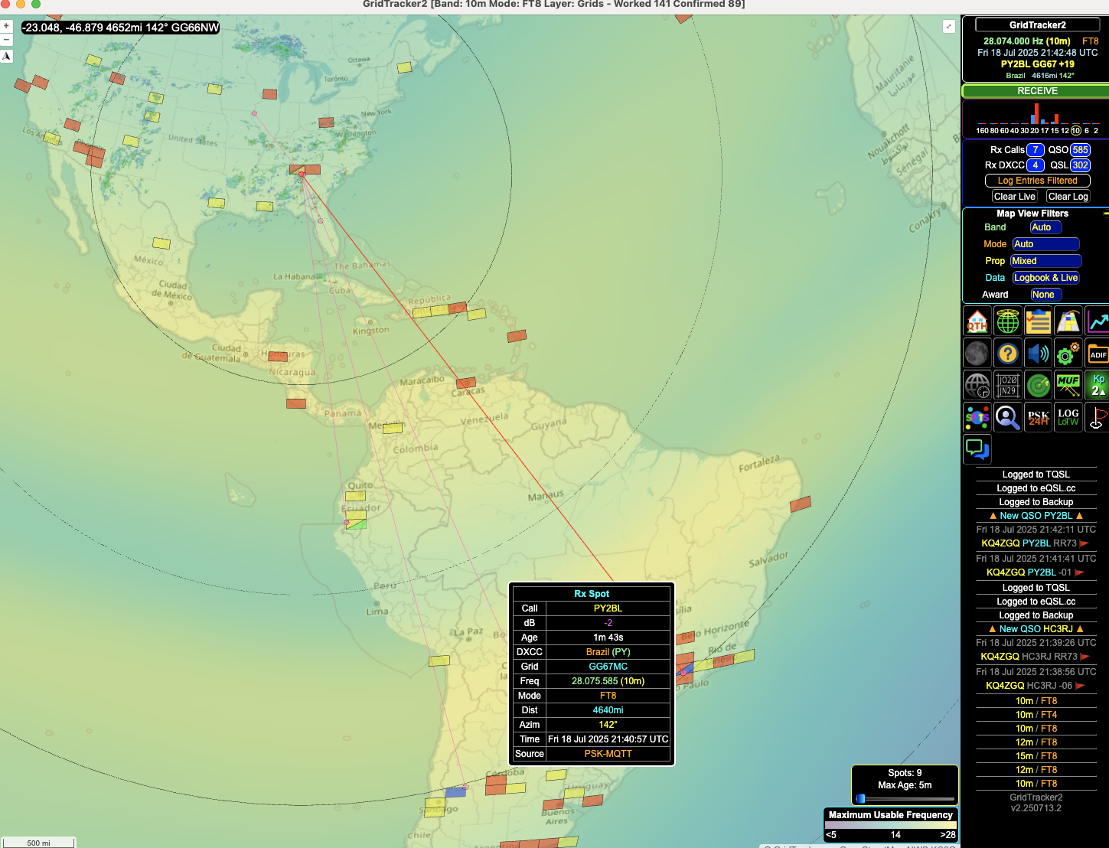
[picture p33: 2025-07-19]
images/testing/brazil-signal.png

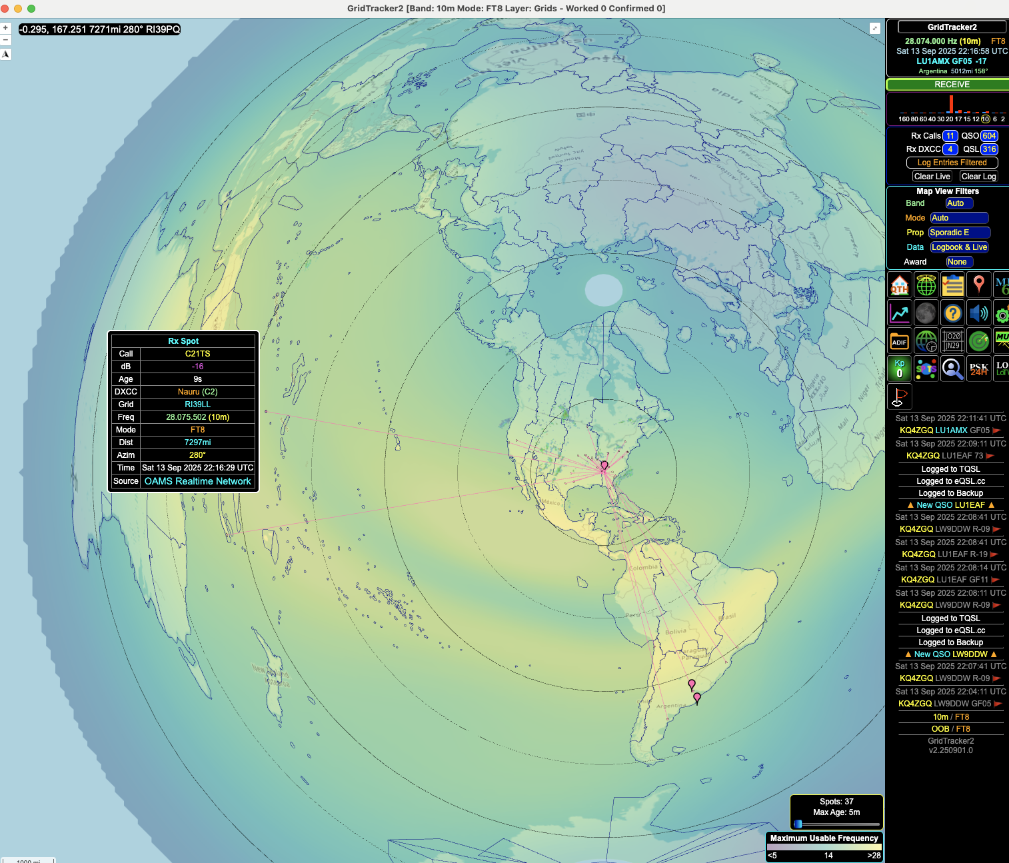
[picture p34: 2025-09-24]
images/testing/nauru.png

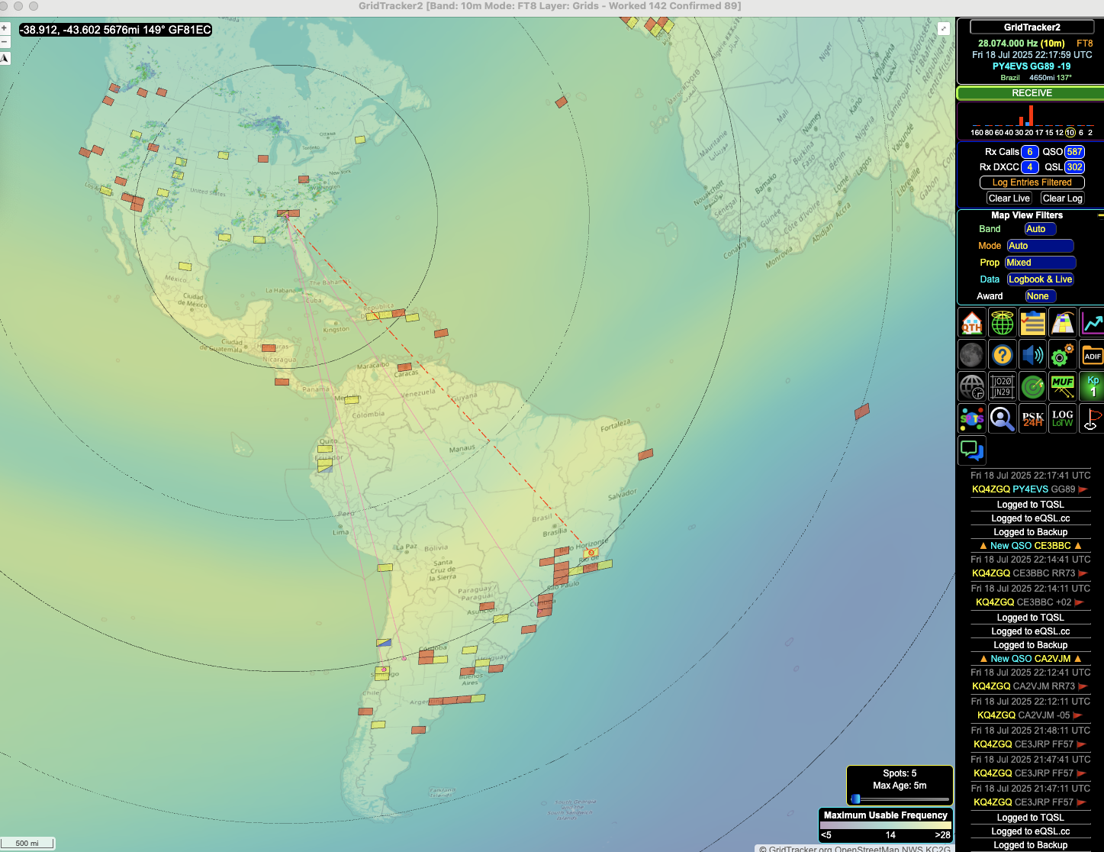
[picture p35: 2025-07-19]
images/testing/brazil2.png

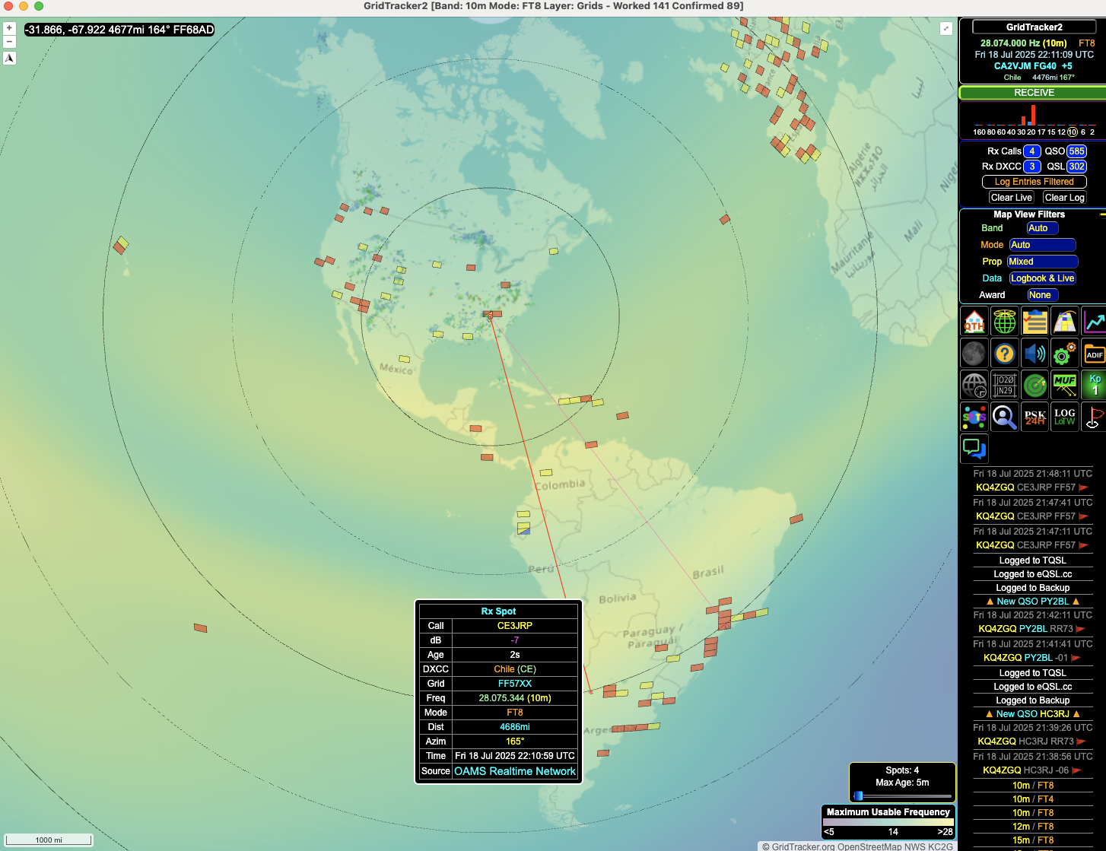
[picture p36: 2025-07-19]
images/testing/chile-signal.png

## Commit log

2025-07-25 updated elements and bill of materials
2025-09-27 added 3dprints
    [10m-yagi-petg-element-cap.stl]
2025-09-27 updated 3dprints
    [10m-yagi-truss-accessories.stl]
2025-09-27 updated 3d prints
    [10m-yagi-rope-tensioner.stl]
2025-09-28 updated pics
    [10m-yagi-boom-mast-clamp.stl, 10m-yagi-truss-base V2.stl]
2025-09-29 updated docs
    [10m-yagi-truss-base-V2.stl]
